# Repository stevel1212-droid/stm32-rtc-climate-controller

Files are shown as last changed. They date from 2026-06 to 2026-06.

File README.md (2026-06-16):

# stm32-rtc-climate-controller

Kicad project (Hardware) and Platform IO project (Firmware) of an STM32-based board climate controller utilizing an RTC module for time-scheduled environmental reading of temperature/humidity with SHT30 sensor and optional small relay for control.



I've ordered the PCBA (SMT assembly only) from JLCPCB and it costs around 62$  for 2 assembled and 3 empty boards with  coupon:


### 🛠️ Tools & Plugins Used:

#### Hardware (KiCad)
* **Footprints & Symbols:** To quickly download components from JLCPCB, I used the [easyeda2kicad](https://github.com/uPesy/easyeda2kicad.py) tool.
* **Manufacturing Files:** To create the fabrication files for PCB and SMD assembly via JLCPCB, I used the [kicad-jlcpcb-tools](https://github.com/bouni/kicad-jlcpcb-tools) external plugin.

#### Firmware (Software)
* **IDE:** Developed using [Visual Studio Code](https://code.visualstudio.com/) with the **PlatformIO IDE** extension.
* **Framework:** Written in C/C++ using the **Arduino Framework** for the STM32F103C8 microcontroller.
* **Peripherals:** Includes support for an SSD1306 OLED display using Adafruit libraries.

---

### 🛒 Hardware Components & Equipment Used:

If you want to build or debug this project, here is the specific hardware and equipment used:

* **Display:** [0.96 inch OLED I2C Display SSD1306](https://www.amazon.com/dp/B0D2RMQQHR?ref_=ppx_hzsearch_conn_dt_b_fed_asin_title_3) - Used for showing temperature, humidity, and time data.
* **RTC Battery:** [Energizer CR2032 Lithium Battery](https://www.amazon.com/dp/B009108SGS?ref=nb_sb_ss_w_as-reorder_k1_1_5&th=1) - Provides backup power to the RTC module to keep time when the main board is powered off.
* **Debugger:** [ST-Link V2 Programmer/Debugger](https://www.amazon.com/dp/B0C9PKJF2T?ref_=ppx_hzsearch_conn_dt_b_fed_asin_title_1&th=1) - Used for flashing the firmware and debugging the STM32.
* **Soldering Iron:** [Pinecil Smart Soldering Iron (BB2)](https://www.amazon.com/dp/B08PZBPXLZ?ref_=ppx_hzsearch_conn_dt_b_fed_asin_title_1&th=1) - Highly recommended portable soldering iron used for assembling the board.

## 🚀 First-Time Setup & Firmware Upload

Follow these steps to flash the firmware and configure the board for the first time:

### 1. Hardware Configuration (Boot Pins)
* Ensure that both **BOOT0** and **BOOT1** jumpers/pins are set to a **logic low** state (GND).

### 2. Connecting the Debugger
* Connect your **ST-Link V2** debugger to the **H1** connector on the board using the following pins: **SWDIO**, **SWCLK**, **3.3V**, and **GND**:


* ⚠️ **CRITICAL:** Do NOT connect the USB-C cable to the board while the debugger is connected and powering the system.

### 3. PlatformIO Configuration (`platformio.ini`)
Open your `platformio.ini` file and adjust the upload settings. You need to enable the ST-Link protocol and comment out the serial configurations:

```ini
# Set the upload protocol to ST-Link
upload_protocol = stlink

# Comment out the serial upload lines
; upload_protocol = serial
; upload_port = COM3
```

### 4. Flashing the Firmware
Plug the ST-Link V2 debugger into your computer's USB port.

In VS Code / PlatformIO, click the Upload button (the right-arrow icon in the bottom status bar) to flash the code to your STM32.

### 5. Setting the Date and Time (RTC Configuration)
Once the firmware is uploaded, disconnect the ST-Link V2 debugger from the board.

Connect the board to your computer using a USB-C cable.

Ensure you have the CP2102 driver installed on your computer so the USB-to-UART bridge is recognized.

Open the Serial Monitor in PlatformIO.

Send the current time and date through the serial terminal using the following exact format: HH:MM:SS DD:MM:YYYY (e.g., 14:30:00 15:06:2026).

### 🎁 Bonus: Serial Flashing (Alternative Method)
Note: This option is only available after the initial first-time flash.
If you prefer to flash future firmware updates directly via USB (Serial) instead of using the ST-Link debugger,
follow these steps:

* Set the BOOT0 pin/jumper to a logic high state (3.3V).
* Press the RESET button on the board to enter the embedded bootloader.
* In your platformio.ini file, switch the comments to enable serial upload:
```Ini
; upload_protocol = stlink
upload_protocol = serial
```
* Click the Upload button in PlatformIO.
* ⚠️ IMPORTANT: Once the upload is finished, you must set the BOOT0 pin back to a logic low state (GND) and press the RESET          button again. Otherwise, the newly uploaded program will not execute upon boot.

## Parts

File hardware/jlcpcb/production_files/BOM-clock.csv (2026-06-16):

Comment | Designator | Footprint | LCSC | Quantity
0603WAF1000T5E | R1 | R0603 | C22775 | 1
0603WAF1001T5E | R12,R15,R18,R20,R21,R24 | R0603 | C21190 | 6
0603WAF1002T5E | R11,R19 | R0603 | C25804 | 2
0603WAF1003T5E | R13,R14,R22 | R0603 | C25803 | 3
0603WAF5101T5E | R16,R17,R23,R25 | R0603 | C23186 | 4
0805G | LED3 | LED0805-R-RD | C2297 | 1
1N4148W_C81598 | D1 | SOD-123F_L2.7-W1.6-LS3.8-RD | C81598 | 1
2N7002 | Q1 | SOT-23-3_L2.9-W1.3-P1.90-LS2.4-BR | C8545 | 1
BAT54C_C22466350 | U10 | SOT-23-3_L2.9-W1.3-P1.90-LS2.8-BR | C22466350 | 1
CC0603KRX7R9BB104 | C15,C16,C18,C21,C23,C24,C25,C26,C27,C28,C29,C30 | C0603 | C14663 | 12
CL10C200JB8NNNC | C19,C20 | C0603 | C1648 | 2
CL21B105KBFNNNE | C14,C22 | C0805 | C28323 | 2
CP2102-GMR | U7 | WQFN-28_L5.0-W5.0-P0.50-BL-EP3.2 | C6568 | 1
CR2032-BS-6 | U11 | BAT-TH_CR2032-BS-6-1 | C22363833 | 1
DSHP02TS-S | SW4 | SW-SMD_DSHP02TS-S | C319052 | 1
FC-2012HRK-620D | LED4 | LED0805-RD | C84256 | 1
G6K-2F-Y-DC5 | K1 | RELAY-SMD_G6K-2F-X-XX | C47190 | 1
H3V3U10B | U2 | DFN1006-2L-BI | C20615782 | 1
PCF8563T/5,518 | U9 | SOIC-8_L5.0-W4.0-P1.27-LS6.0-BL | C7440 | 1
Q13FC1350000400 | X3 | FC-135R_L3.2-W1.5 | C32346 | 1
SHT30-DIS-B | U8 | DFN-8_L2.5-W2.5-P0.50-BL-EP | C77361 | 1
STC3MD20-T1 | C17 | CAP-SMD_L4.5-W3.2_STC3MD20-T1 | C22468122 | 1
STM32F103C8T6 | U3 | LQFP-48_L7.0-W7.0-P0.50-LS9.0-BL | C8734 | 1
TS-1088-AR02016 | SW3 | SW-SMD_L3.9-W3.0-P4.45 | C720477 | 1
TYPE-C 16PIN 2MD | USB2 | USB-C-SMD_TYPE-C-6PIN-2MD-073 | C2765186 | 1
X50328MSB2GI | X2 | CRYSTAL-SMD_L5.0-W3.2 | C115962 | 1
XC6206P332MR | U1 | SOT-23-3_L2.9-W1.6-P1.90-LS2.8-BR | C5446 | 1

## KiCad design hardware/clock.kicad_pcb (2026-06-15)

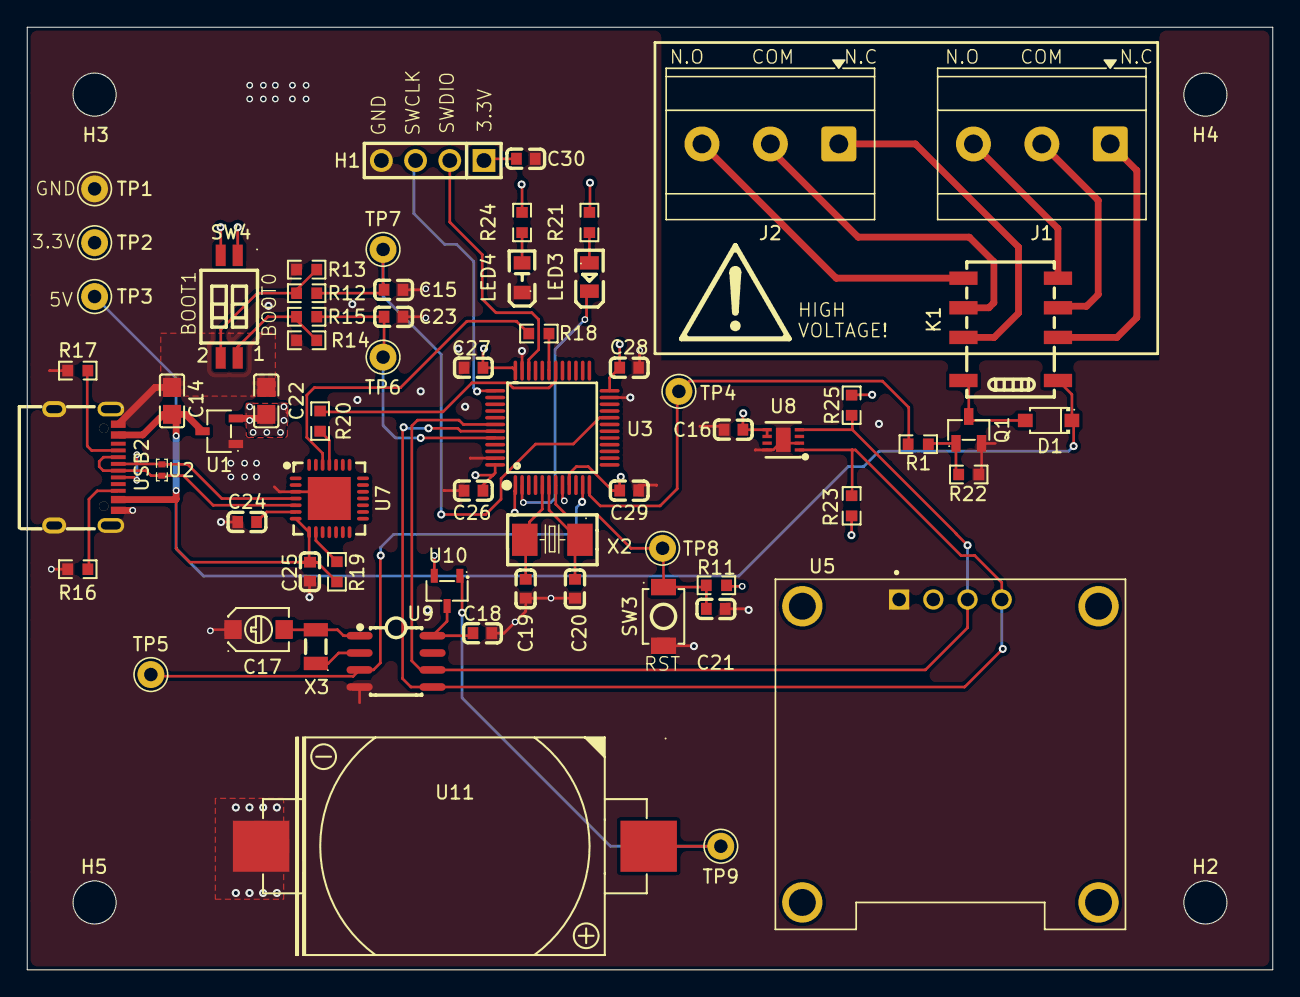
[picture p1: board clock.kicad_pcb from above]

Board: 4 copper layers, 92.5 x 70.0 mm, 68 parts (0 on the bottom side), 41 nets.

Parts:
C14, C22: CL21B105KBFNNNE; C0805
C15, C16, C18, C21, C23, C24, C25, C26, C27, C28, C29, C30: CC0603KRX7R9BB104; C0603
C17: STC3MD20-T1; CAP-SMD_L4.5-W3.2_STC3MD20-T1
C19, C20: CL10C200JB8NNNC; C0603
D1: 1N4148W_C81598; SOD-123F_L2.7-W1.6-LS3.8-RD
H1: PZ254V-11-04P_C2691448; HDR-TH_4P-P2.54-V-M
H2, H3, H4, H5: MountingHole; MountingHole_3.2mm_M3
J1, J2: Screw_Terminal_01x03; TerminalBlock_MetzConnect_Type073_RT02603HBLU_1x03_P5.08mm_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
K1: G6K-2F-Y-DC5; RELAY-SMD_G6K-2F-X-XX
LED3: 0805G; LED0805-R-RD
LED4: FC-2012HRK-620D; LED0805-RD
Q1: 2N7002; SOT-23-3_L2.9-W1.3-P1.90-LS2.4-BR
R1: 0603WAF1000T5E; R0603
R11, R19: 0603WAF1002T5E; R0603
R12, R15, R18, R20, R21, R24: 0603WAF1001T5E; R0603
R13, R14, R22: 0603WAF1003T5E; R0603
R16, R17, R23, R25: 0603WAF5101T5E; R0603
SW3: TS-1088-AR02016; SW-SMD_L3.9-W3.0-P4.45
SW4: DSHP02TS-S; SW-SMD_DSHP02TS-S
TP1, TP2, TP3, TP4, TP5, TP6, TP7, TP8, TP9: TestPoint; Pin_D1.0mm_L10.0mm
U1: XC6206P332MR; SOT-23-3_L2.9-W1.6-P1.90-LS2.8-BR
U2: H3V3U10B; DFN1006-2L-BI
U3: STM32F103C8T6; LQFP-48_L7.0-W7.0-P0.50-LS9.0-BL
U5: DM-OLED096-636; MODULE_DM-OLED096-636
U7: CP2102-GMR; WQFN-28_L5.0-W5.0-P0.50-BL-EP3.2
U8: SHT30-DIS-B; DFN-8_L2.5-W2.5-P0.50-BL-EP
U9: PCF8563T/5,518; SOIC-8_L5.0-W4.0-P1.27-LS6.0-BL
U10: BAT54C_C22466350; SOT-23-3_L2.9-W1.3-P1.90-LS2.8-BR
U11: CR2032-BS-6; BAT-TH_CR2032-BS-6-1
USB2: TYPE-C 16PIN 2MD; USB-C-SMD_TYPE-C-6PIN-2MD-073
X2: X50328MSB2GI; CRYSTAL-SMD_L5.0-W3.2
X3: Q13FC1350000400; FC-135R_L3.2-W1.5

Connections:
+3.3V: C16.2, C22.2, C26.2, C27.2, C28.2, C29.2, C30.1, H1.1, R11.2, R21.2, R23.2, R24.2, R25.2, SW4.1, SW4.2, TP2.1 (1_1), U1.2 (Vout), U3.1 (VBAT), U3.9 (VDDA), U3.24 (VDD_1), U3.36 (VDD_2), U3.48 (VDD_3), U5.2 (VCC_IN), U8.5 (VDD), U8.6 (nRESET), U10.2 (A)
+5V: C14.2, C25.2, D1.1 (K), K1.1, R19.1, TP3.1 (1_1), U1.3 (Vin), U7.7 (REGIN), U7.8 (VBUS), USB2.2 (VBUS), USB2.11 (VBUS)
/mcu/BOOT0: C23.2, R15.2, TP6.1 (1_1), U3.44 (BOOT0)
/mcu/BOOT1: C15.2, R12.1, TP7.1 (1_1), U3.20 (PB2)
/mcu/DN: U2.1, U7.5 (D-), USB2.5 (DN2), USB2.7 (DN1)
/mcu/DP: U2.2, U7.4 (D+), USB2.6 (DP1), USB2.8 (DP2)
/mcu/NRST: C21.2, R11.1, SW3.2, TP8.1 (1_1), U3.7 (NRST)
/mcu/OSC_IN: C19.2, U3.5 (PD0-OSC_IN), X2.2 (OSC2)
/mcu/OSC_OUT: C20.2, U3.6 (PD1-OSC_OUT), X2.1 (OSC1)
/mcu/PA1: TP5.1 (1_1), U3.11 (PA1), U9.3 (~INT)
/mcu/PA2: R1.1, TP4.1 (1_1), U3.12 (PA2)
/mcu/PA9: R20.2, U3.30 (PA9)
/mcu/PA10: R18.2, U3.31 (PA10)
/mcu/PC13: LED3.2 (K), U3.2 (PC13-TAMPER-RTC)
/mcu/SCL: R25.1, U3.42 (PB6), U5.3 (SCL), U8.4 (SCL), U9.6 (SCL)
/mcu/SDA: R23.1, U3.43 (PB7), U5.4 (SDA), U8.1 (SDA), U9.5 (SDA)
/mcu/SWCLK: H1.3, U3.37 (PA14)
/mcu/SWIO: H1.2, U3.34 (PA13)
GND: C14.1, C15.1, C16.1, C17.1, C18.1, C19.1, C20.1, C21.1, C22.1, C23.1, C24.1, C25.1, C26.1, C27.1, C28.1, C29.1, C30.2, H1.4, LED4.1 (-), Q1.2 (S), R13.1, R14.1, R16.2, R17.2, R22.1, SW3.1, TP1.1 (1_1), U1.1 (GND), U3.8 (VSSA), U3.23 (VSS_1), U3.35 (VSS_2), U3.47 (VSS_3), U5.1 (GND), U7.3 (GND), U7.29 (EP), U8.2 (ADDR), U8.8 (VSS), U8.9 (EPAD), U9.4 (VSS), U11.2, USB2.1 (GND), USB2.12 (GND), USB2.13 (SHELL), USB2.14 (SHELL)
unnamed: D1.2 (A), K1.8, Q1.3 (D)
unnamed: J1.1, K1.2
unnamed: J1.2, K1.3
unnamed: J1.3, K1.4
unnamed: J2.1, K1.7
unnamed: J2.2, K1.6
unnamed: J2.3, K1.5
unnamed: LED3.1 (A), R21.1
unnamed: LED4.2 (+), R24.1
unnamed: Q1.1 (G), R1.2, R22.2
unnamed: R12.2, R13.2, SW4.3
unnamed: R14.2, R15.1, SW4.4
unnamed: TP9.1 (1_1), U10.1 (A), U11.1
unnamed: R20.1, U7.25 (RXD)
unnamed: R18.1, U7.26 (TXD)
unnamed: C24.2, U7.6 (VDD)
unnamed: R19.2, U7.9 (~RST)
unnamed: C17.2, U9.1 (OSCI), X3.2
unnamed: U9.2 (OSCO), X3.1
unnamed: C18.2, U9.8 (VDD), U10.3 (K)
unnamed: R17.1, USB2.4 (CC1)
unnamed: R16.1, USB2.10 (CC2)

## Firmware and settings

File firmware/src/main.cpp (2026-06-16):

#include <Arduino.h>
#include <Wire.h>
#include <Adafruit_GFX.h>
#include <Adafruit_SSD1306.h>

#define SCREEN_WIDTH 128 
#define SCREEN_HEIGHT 64

#define LED_PIN PC13
#define RELAY_PIN PA2
#define PCF8563_ADDR 0x51      // RTC I2C address
#define SHT30_ADDR 0x44         // Temperature sensor I2C address

Adafruit_SSD1306 display(SCREEN_WIDTH, SCREEN_HEIGHT, &Wire, -1);

// Time variables
int hours = 22;
int minutes = 9;
int seconds = 0;
int day = 19, month = 5, year = 2026;
unsigned long lastUpdate = 0;
float temperature = 0.0;
float humidity = 0.0;




// ========== BCD Conversion ==========
byte decToBcd(byte val) {
  return ((val / 10 * 16) + (val % 10));
}

byte bcdToDec(byte val) {
  return ((val / 16 * 10) + (val % 16));
}

// ========== PCF8563 RTC Functions ==========
void initRTC() {
  Wire.beginTransmission(PCF8563_ADDR);
  Wire.write(0x00); // Control register 1
  Wire.write(0x00); // Clear control bits, enable RTC
  Wire.endTransmission();
  
  // Check and clear VL (Voltage Low) bit
  Wire.beginTransmission(PCF8563_ADDR);
  Wire.write(0x02); // Seconds register
  Wire.endTransmission();
  
  Wire.requestFrom(PCF8563_ADDR, 1);
  byte seconds_byte = Wire.read();
  
  if (seconds_byte & 0x80) { // VL bit is set, need to reset it
    Wire.beginTransmission(PCF8563_ADDR);
    Wire.write(0x02); // Seconds register
    Wire.write(seconds_byte & 0x7F); // Clear VL bit
    Wire.endTransmission();
  }
}

void setTimeRTC(int h, int m, int s, int d, int mo, int y) {
  Wire.beginTransmission(PCF8563_ADDR);
  Wire.write(0x02); // Start at seconds register
  Wire.write(decToBcd(s) & 0x7F);      // Seconds (clear VL bit)
  Wire.write(decToBcd(m) & 0x7F);      // Minutes
  Wire.write(decToBcd(h) & 0x3F);      // Hours (24-hour format)
  Wire.write(decToBcd(d) & 0x3F);      // Day
  Wire.write(0x00);                     // Weekday (0-6, not used here)
  Wire.write(decToBcd(mo) & 0x1F);     // Month
  Wire.write(decToBcd(y - 2000));      // Year (0-99)
  Wire.endTransmission();
}

void readTimeFromRTC() {
  Wire.beginTransmission(PCF8563_ADDR);
  Wire.write(0x02); // Start reading from seconds register
  Wire.endTransmission();
  
  Wire.requestFrom(PCF8563_ADDR, 7); // Request 7 bytes
  if (Wire.available() >= 7) {
    seconds = bcdToDec(Wire.read() & 0x7F); // Remove VL bit
    minutes = bcdToDec(Wire.read() & 0x7F);
    hours = bcdToDec(Wire.read() & 0x3F);   // Remove hour format bit
    day = bcdToDec(Wire.read() & 0x3F);
    Wire.read(); // Skip weekday
    month = bcdToDec(Wire.read() & 0x1F);   // Remove century bit
    year = 2000 + bcdToDec(Wire.read());
  }
}

// ========== SHT30 Temperature/Humidity Functions ==========
void initSHT30() {
  Wire.beginTransmission(SHT30_ADDR);
  Wire.write(0x22); // Soft reset command high byte
  Wire.write(0x36); // Soft reset command low byte
  Wire.endTransmission();
  delay(10);
}

void readTemperatureHumidity() {
  // Trigger measurement: periodic mode with 0.5 mps
  Wire.beginTransmission(SHT30_ADDR);
  Wire.write(0x21); // Command high byte
  Wire.write(0x30); // Command low byte
  Wire.endTransmission();
  
  delay(20); // Wait for measurement
  
  Wire.requestFrom(SHT30_ADDR, 6); // Request 6 bytes (temp(2) + checksum + humidity(2) + checksum)
  if (Wire.available() >= 6) {
    uint16_t tempRaw = (Wire.read() << 8) | Wire.read();
    Wire.read(); // Skip checksum
    uint16_t humidityRaw = (Wire.read() << 8) | Wire.read();
    Wire.read(); // Skip checksum
    
    // Convert temperature (in 0.01°C)
    temperature = -45.0 + (175.0 * tempRaw / 65535.0);
    // Convert humidity (in 0.1%)
    humidity = 100.0 * humidityRaw / 65535.0;
  }
}

// put function declarations here:





void setup() {
  // put your setup code here, to run once:
  Serial.setTx(PA9); // מגדיר את המשדר של הבקר לפין PA10 (היכן שחיברת את ה-RX של ה-USB)
  Serial.setRx(PA10);  // מגדיר את הקולט של הבקר לפין PA9 (היכן שחיברת את ה-TX של ה-USB)
  Serial.begin(115200);
  delay(1000);
  
  Serial.println("\n\n=== DEVICE STARTING ===");
  
  pinMode(LED_PIN, OUTPUT);
  pinMode(RELAY_PIN, OUTPUT);
  digitalWrite(RELAY_PIN, LOW);  // Default relay OFF
  Wire.setSDA(PB7);
  Wire.setSCL(PB6);
  Wire.begin();
  
  if(!display.begin(SSD1306_SWITCHCAPVCC, 0x3C))
    for(;;); // עצירה אם המסך לא נמצא
  
  display.clearDisplay();
  display.setTextSize(1);
  display.setTextColor(SSD1306_WHITE);
  display.setCursor(0, 0);
  display.println("SEND TIME:");
  display.println("HH:MM:SS DD:MM:YYYY");
  display.println("");
  display.println("Waiting 10 seconds...");
  display.display();
  
  Serial.println("\n=== PCF8563 TIME SYNC ===");
  Serial.println("Send time in format:");
  Serial.println("HH:MM:SS DD:MM:YYYY");
  Serial.println("Example: 15:06:00 14:06:2026");
  Serial.println("Waiting 10 seconds...\n");
  
  // Initialize sensors
  initRTC();
  delay(50);
  
  // Wait for time from PC (send format: "HH:MM:SS DD:MM:YYYY")
  unsigned long waitStart = millis();
  String timeStr = "";
  bool timeReceived = false;
  
  while (millis() - waitStart < 10000) { // Wait 10 seconds for time input
    if (Serial.available()) {
      char c = Serial.read();
      Serial.write(c); // Echo the character
      
      if (c == '\n' || c == '\r') {
        Serial.print("Received string length: ");
        Serial.println(timeStr.length());
        Serial.print("Content: [");
        Serial.print(timeStr);
        Serial.println("]");
        
        if (timeStr.length() >= 19) {
          timeReceived = true;
          break;
        }
      } else {
        timeStr += c;
      }
    }
  }
  
  Serial.println("Timeout reached.");
  
  // Parse time string if received
  if (timeReceived && timeStr.length() >= 19) {
    Serial.println("Parsing time...");
    int h = (timeStr[0] - '0') * 10 + (timeStr[1] - '0');
    int m = (timeStr[3] - '0') * 10 + (timeStr[4] - '0');
    int s = (timeStr[6] - '0') * 10 + (timeStr[7] - '0');
    int d = (timeStr[9] - '0') * 10 + (timeStr[10] - '0');
    int mo = (timeStr[12] - '0') * 10 + (timeStr[13] - '0');
    int y = (timeStr[15] - '0') * 1000 + (timeStr[16] - '0') * 100 + 
            (timeStr[17] - '0') * 10 + (timeStr[18] - '0');
    
    Serial.print("Parsed: ");
    Serial.print(h); Serial.print(":");
    Serial.print(m); Serial.print(":");
    Serial.print(s); Serial.print(" ");
    Serial.print(d); Serial.print("/");
    Serial.print(mo); Serial.print("/");
    Serial.println(y);
    
    setTimeRTC(h, m, s, d, mo, y);
    Serial.print("RTC time set to: ");
    Serial.println(timeStr);
    
    display.clearDisplay();
    display.setCursor(0, 0);
    display.println("Time set!");
    display.print(timeStr.substring(0, 8));
    display.display();
    delay(1000);
  } else {
    Serial.println("No valid time received.");
    display.clearDisplay();
    display.setCursor(0, 0);
    display.println("No time received");
    display.println("Waiting for input...");
    display.display();
  }
  
  delay(50);
  initSHT30();
  delay(100);
}

void loop() {
  // LED blink: 5 seconds ON, 5 seconds OFF
  static unsigned long lastLedToggle = 0;
  static bool ledState = HIGH;
  
  if (millis() - lastLedToggle >= 1000) {
    lastLedToggle = millis();
    ledState = !ledState;
    digitalWrite(LED_PIN, ledState);
  }
  
  // Relay: ON for 20 seconds every round hour (minute=0, seconds=0-19)
  if (minutes == 0 && seconds < 20) {
    digitalWrite(RELAY_PIN, HIGH);
  } else {
    digitalWrite(RELAY_PIN, LOW);
  }
  
  // Check for serial commands to update time
  if (Serial.available()) {
    String cmd = Serial.readStringUntil('\n');
    if (cmd.length() >= 19) {
      int h = (cmd[0] - '0') * 10 + (cmd[1] - '0');
      int m = (cmd[3] - '0') * 10 + (cmd[4] - '0');
      int s = (cmd[6] - '0') * 10 + (cmd[7] - '0');
      int d = (cmd[9] - '0') * 10 + (cmd[10] - '0');
      int mo = (cmd[12] - '0') * 10 + (cmd[13] - '0');
      int y = (cmd[15] - '0') * 1000 + (cmd[16] - '0') * 100 + 
              (cmd[17] - '0') * 10 + (cmd[18] - '0');
      setTimeRTC(h, m, s, d, mo, y);
      Serial.println("Time updated!");
    }
  }
  
  if (millis() - lastUpdate >= 1000) {
    lastUpdate = millis();
    
    // Read time from RTC
    readTimeFromRTC();
    
    // Read temperature from SHT30 every 5 seconds
    static unsigned long lastTempRead = 0;
    if (millis() - lastTempRead >= 5000) {
      lastTempRead = millis();
      readTemperatureHumidity();
    }

    display.clearDisplay();
    
    // --- Display Time (top) ---
    display.setTextSize(2);
    display.setTextColor(SSD1306_WHITE);
    display.setCursor(16, 0);
    if(hours < 10) display.print("0"); display.print(hours);
    display.print(":");
    if(minutes < 10) display.print("0"); display.print(minutes);
    display.print(":");
    if(seconds < 10) display.print("0"); display.print(seconds);

    // --- Display Date (middle) ---
    display.setTextSize(1);
    display.setCursor(0, 25);
    if(day < 10) display.print("0"); display.print(day);
    display.print("/");
    if(month < 10) display.print("0"); display.print(month);
    display.print("/");
    display.print(year);
    
    // --- Display Temperature and Humidity (bottom) ---
    display.setCursor(0, 40);
    display.print("T:");
    display.print(temperature, 1);
    display.println("C");
    
    display.setCursor(0, 50);
    display.print("H:");
    display.print(humidity, 0);
    display.println("%");

    display.display();
  }
}

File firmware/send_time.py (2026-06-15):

#!/usr/bin/env python3
"""
Send current PC time to STM32 microcontroller via Serial.
Format: HH:MM:SS DD:MM:YYYY
"""

import serial
import sys
from datetime import datetime

# Configuration
PORT = 'COM3'  # Change this to your COM port
BAUD_RATE = 115200

def send_time(port=PORT, baud=BAUD_RATE):
    """Send current PC time to device"""
    try:
        ser = serial.Serial(port, baud, timeout=2)
        
        # Get current time from PC
        now = datetime.now()
        time_str = now.strftime("%H:%M:%S %d:%m:%Y")
        
        print(f"Sending time to {port}: {time_str}")
        
        # Send with newline
        ser.write((time_str + "\n").encode())
        
        # Wait for response
        response = ser.readline().decode().strip()
        if response:
            print(f"Device response: {response}")
        
        ser.close()
        print("Done!")
        
    except Exception as e:
        print(f"Error: {e}")
        sys.exit(1)

if __name__ == "__main__":
    if len(sys.argv) > 1:
        send_time(sys.argv[1])
    else:
        send_time()

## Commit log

2026-06-15 Add README for Kicad project files
2026-06-15 Update README with RTC battery details and tools
    Added RTC battery information and updated tools list.
